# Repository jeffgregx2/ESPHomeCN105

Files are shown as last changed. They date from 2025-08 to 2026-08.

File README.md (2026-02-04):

# Mitsubishi CN105 ESPHome Hardware Microcontroller

This project is inspired by the work done by [@echavet](https://github.com/echavet/MitsubishiCN105ESPHome) and [@GeoffDavis](https://github.com/geoffdavis/esphome-mitsubishiheatpump) (and others) reverse engineering the CN105 serial protocol for the Mitsubishi Split-Mini heat pumps.  Their work allows for complete control of those units via ESPHome instead of the Kumo Cloud offering from Mitsubishi.  One can argue that the ESPHome offering is superior including the ability to have complete control over important logic such as room temperature settings, etc.

## Quick Links

 - Setting up ESPHome/Home Assistant - [Configuration](/home_assistant/)
 - Pre-made Hardware - [ETSY]() (Coming Soon) 
 - Building the Hardware - DIY/PCBWay:  
    - [PAC-USWHS002-WF-1 Compatible module](https://www.pcbway.com/project/shareproject/Mitsubishi_ESPHome_CN105_Microcontroller_kicad_pcb_b5b72995.html)
    - [PAC-USWHS002-WF-2 Compatible module](https://www.pcbway.com/project/shareproject/Mitsubishi_ESPHome_CN105_Microcontroller_PAC_USWHS002_WF_2_plug_compatible_8670e686.html)

## Hardware
In order to use the ESPHome approach, appropriate hardware needs to be assembled and installed in (or next to) each split-mini to be controlled.  Most take DevKits and breadboards or otherwise construct controllers to be installed.  However I wanted something more production ready that was plug compatible with the Mitsubishi PAC-USWHS002-WF-1 and PAC-USWHS002-WF-2 wifi modules and had the exact same footprint allowing easy swapping between modules.

To this end I have designed a PCB board using an ESP32-C6 devkit and associated 3D printed case that is the same size of the module it is replacing as well as plug compatible.  If you already have the PAC-USWHS002-WF-1 or WF-2 module installed, you can simply unplug that module and plug this new module into its place.  In addition, this new module exposes an i2c port via a [STEMMA](https://learn.adafruit.com/introducing-adafruit-stemma-qt/what-is-stemma) compatible connector.   For more information on the PCB design, 3D case, etc. and how to create your own copy of the board please see [PCB_assembly](/pcb_assembly/).

## Software

In addition, I have included ESPHome include files that allow assembling thermostat devices for this device in Home Assistant far easier and repeatable - very helpful if you have multiple devices.  The result allows for YAML files that only contain substitutions and secret references.  The files and additional documentation is available [HERE](/home_assistant/).

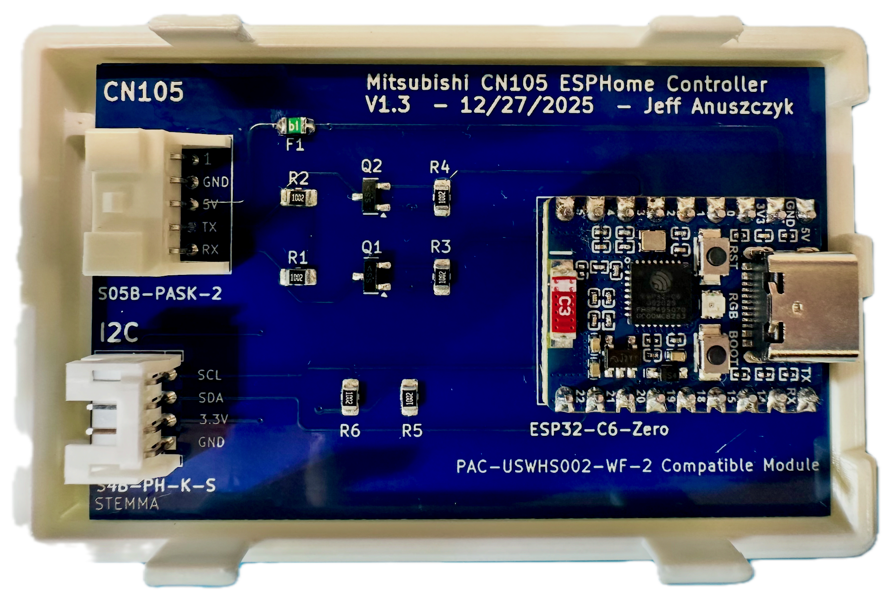
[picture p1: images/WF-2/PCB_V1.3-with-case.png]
PCB Board described above


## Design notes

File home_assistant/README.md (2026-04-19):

# ESPHome - Home Assistant Support
Once you have the appropriate hardware to support the ESPHomeCN105 firmware, you need to setup the appropriate YAML files in ESPHome.  In my case this is attached to [Home Assistant](https://www.home-assistant.io) making it effortless to both interact as well as make other devices available such as temperature sensors.  While you may only have one (1) split-mini wall unit, once you have two (2) or more units setting up the configurations can result in lots of duplication, etc. between the various YAML files.  To help minimize this I have created a set of include files that hopefully make reuse across multiple device simple and straightforward.  

All of the configuration needed to use these include files is done via the substition command within ESPHome YAML files. This allows for high reusability of code within the devices being created which will hopefully reduce bugs and enable the devices to behave similarly.

Please note that these files are aligned to the hardware described in [PCB_assembly](/pcb_assembly/) and specifically the use of the ESP32-C6 dev kit.  If you are using different hardware slight tweaks will be required.

##  Overview
The functionality provided by the defined YAML files includes:
* Climate device for Mitsubishi CN105 split-mini
* LED status indicator: Red = not connected to CN105, Green = Connected : blinks every 1.5 seconds
* Home Assistant API integration
* Remote Temperature sensor definition and logic to update CN105 periodically to ensure split-mini internal sensor is not used if a valid remote sensor value is available.
* i2c bus initialization to allow i2c sensors to be installed and used
* Various diagnostic information reported to Home Assistant

There are multiple include files that break up the functionality allowing you to load those portions that you need.  These files are as follows:
* **mitsubishi_cn105_device_base.yaml** - Required - this is the core include file that you must always load containing all of the climate device definitions. 
* **mitsubishi_cn105_config.yaml** - Required - this contains the hardware module definitions, logging, web server definitions as well as home assistant integration.  Note that this file is aligned to the ESP32-c6 dev kit and would need modification to work with other boards.
* **One of the following:**
	* **mitsubishi_cn105_remote_temp.yaml** -  this connects to a home assistant device that will provide temperature sensor information that will be used to set the remote temperature in the climate device. 
	* **mitsubishi_cn105_remote_temp_dual.yaml** - a more sophisticated version of mitsubishi_cn105_remote_temp.yaml that support two (2) remote sensor devices that can be setup as either a primary/backup configuration or an average of the two.  This is useful in situations in which one of the sensors is not entirely accurate but you would prefer an external temperature vs the internal sensor from the split mini (which tends to not be accurate).
	* **mitsubishi_cn105_remote_temp_none.yaml** - indicates that no remote temperature device will be used.
* **One of the following:**
   Since WiFi is required, either the static or dynamic configuration must be included (but only one of them!).
	* **mitsubishi_cn105_wifi_dynamic.yaml** - This include file sets up DHCP provisioning of the network address.  In many situations this is the best option.  If you have a "flat" network (i.e., home router/wifi that everything directly connects to) this will work well.
	* **mitsubishi_cn105_wifi_static.yaml** - This include file sets up the use of static IP address for the device - DHCP is disabled!  If you have separated your ESPHome/IoT devices into a different network (VLAN, etc.) assigning static IP addresses is by far the best approach to ensure reliable connection via the ESPHome Builder.  It will require you recording the IP addresses you have assigned to ensure that two devices don't get the same IP address (this will break things).

While this looks like a lot, take a look at the examples which will demonstrate usage that is hopefully very straightforward.

## Installation
There are two ways you can use the include files in your Home Assistant configuration:
1. **REMOTE** - Referenced directly from the files stored in GitHub, nothing is installed locally except for the device's YAML file.  The primary advantage is nothing to install locally, just create the normal device YAML file and reference the GitHub include files.  Unless you plan on making local changes this is likely the best approach.
2. **LOCAL** - Installed directly in Home Assistant and locally referenced within a device's YAML file.  The examples in this README are using local copies of the files.  The primary advantage to using local files is the ability to make local changes to core files.  However it requires substantially more work to deploy new updates from GitHub should they occur since you need to merge the changes together.

### Installing locally
In order to reference the include files in your device YAML file, you need to place all of the files located at [home_assistant/common](/home_assistant/common/) into an appropriate location in Home Assistant using either the terminal or a tool such as the [File Editor Add-On](https://github.com/home-assistant/addons?tab=readme-ov-file).

It is recommended that you copy the files to homeassistant/esphome/common (creating the 'common' directory first).  Once you have uploaded the files you should see them as follows (this examples uses File Editor):

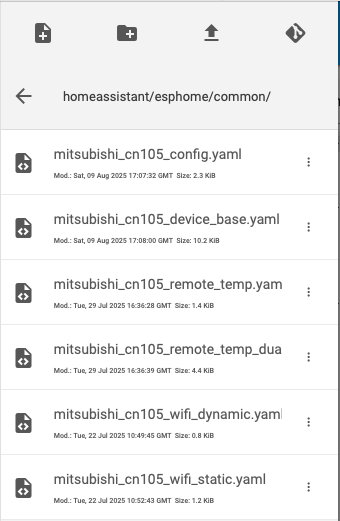
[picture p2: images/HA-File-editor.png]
File Editor example


## Simple Usage
In the simplest of cases, you can define a climate device with no remote sensors as follows:
### Remote include files
```
#
# Load the device configuration for Mitsubishi CN105 Controller.  This is a direct
# replacement for Mitsubishi Kumo Cloud Wifi Controller (Model PAC-USWHS002-WF-1/WF-2)
#
packages:
  - github://jeffgregx2/ESPHomeCN105/home_assistant/common/mitsubishi_cn105_config.yaml@v1.2
  - github://jeffgregx2/ESPHomeCN105/home_assistant/common/mitsubishi_cn105_wifi_dynamic.yaml@v1.2
  - github://jeffgregx2/ESPHomeCN105/home_assistant/common/mitsubishi_cn105_remote_temp_none.yaml@v1.2
  - github://jeffgregx2/ESPHomeCN105/home_assistant/common/mitsubishi_cn105_device_base.yaml@v1.2

# The packages have requirements regarding substitutions that need to be answered.
substitutions:
  name: midu-climate-guest-bedroom
  friendly_name: Mitsubishi Guest Bedroom
  
  # Wifi Setup - static configuration
  wifi_ssid: !secret wifi_iot_ssid
  wifi_password: !secret wifi_iot_password

  # Wifi Access Point Fallback
  wifi_ap_fallback_ssid: !secret fallback_ssid_midu_guest_bedroom
  wifi_ap_fallback_password: !secret fallback_password_midu_guest_bedroom

  # Various passwords
  api_key: !secret api_key_midu_guest_bedroom
  ota_key: !secret ota_key_midu_guest_bedroom

  # Setup web server authentication
  # To disable the web server add the following after the substitution section:
  #     web_server: !remove
  ws_username: !secret web_server_username
  ws_password: !secret web_server_password

 # Disable the web server component
web_server: !remove
```
Please note the '@v1.2' indicates that you only want version 1.2.  If you are not familiar with Git, this is a "tag" that was created to mark files at a specific point in time with a name (in this case "v1.2").  If you use "@main" then you would be using the latest version available in the repository.  By specifying a specific version you reduce the chances of breaking changes within the include files.  However you might miss an enhancement or a fix needed to maintain compatibility with the ESPHome and Home Assistant requiring manual intervention.

### Local include files
The only changes necessary to move to a local directory are in the packages definition:
```
packages:
  - !include common/mitsubishi_cn105_config.yaml
  - !include common/mitsubishi_cn105_wifi_dynamic.yaml
  - !include common/mitsubishi_cn105_remote_temp_none.yaml
  - !include common/mitsubishi_cn105_device_base.yaml
```
The directory specified must match the location you copied in the files in the [Installing Locally](#installing-locally) section.

## Detailed Examples
Click [HERE](/home_assistant/examples/) or more detailed examples

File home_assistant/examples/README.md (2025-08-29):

# Mitsubishi CN105 ESPHome - Examples
For simplicity, all examples use the Secret facility to store the differences between devices.  Mostly these are usernames and passwords - however they can include things like wifi SSID, etc.  Since these examples are public using Secrets allows for valid values while minimizing my ability to accidentally reveal information :-)

This directory provides the following examples:
* **midu-climate-simple.yaml** - essentially the minimal amount needed to setup a Mitsubishi Split Mini using the [ESPHomeCN105 firmware](https://github.com/echavet/MitsubishiCN105ESPHome).  This will require the include files to be [installed](/home_assistant/README.md#installing-locally) on your local Home Assistant server.  No temperature sensor is provided - only the internal sensor on the split mini will be available.
* **midu-climate-simple-git.yaml** - the same example as midu-climate-simple.yaml, except using GitHub to serve the include files instead of installing them locally.
* **midu-climate-simple_i2c.yaml** - the simple example now leveraging an i2c temperature sensor to set the local temperature instead of a Home Assistant sensor.
* **climate-simple-remote-temp.yaml** - the simple example with an added Home Assistant temperature sensor providing the temp to use in place of the split mini internal sensor.
* **midu-climate-dual-sensor.yaml** - a slightly more complex example in which two (2) Home Assistant temperature sensors are providing the temp to use in place of the split mini internal sensor.  The example averages the two temp together (if they are both available, if only one is available it alone is used).
* **midu-climate-complex-temp.yaml** - this demonstrates handling multiple temperature sensors within the device YAML exclusively adding more complex logic that decides what to do based upon the status of the split mini.
* **midu-climate-wifi-static.yaml** - all prior examples use dynamic WIFI (i.e., DHCP) to get an IP address on your network.  This example moves to static IP addresses which is highly useful when you have multiple subnets that are firewalled from each other.  This can cause mDNS (i.e., Bonjour) to not be available and thus the communications between HA/ESPHome to not be reliable (or work).  If you are using static IP addresses it is strongly advised that you also define a domain name via the wifi_domain variable.  The default is '.local' which is aligned with mDNS and may cause discovery to still not work.

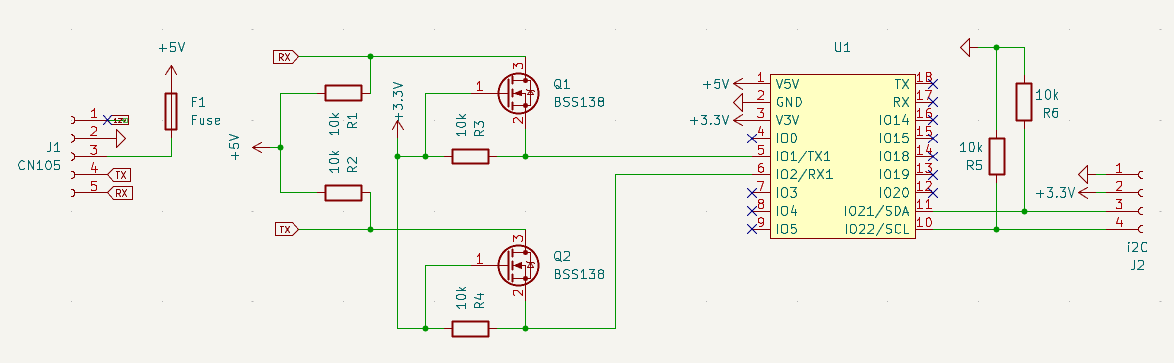
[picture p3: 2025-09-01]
images/WF-1/PCB-schematic.png

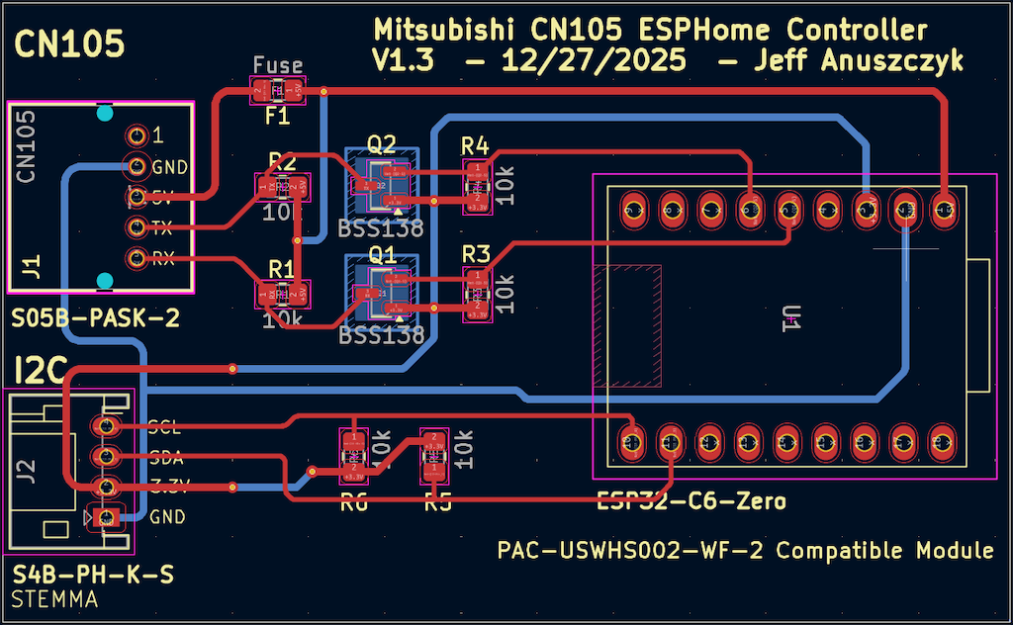
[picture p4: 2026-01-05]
images/WF-2/PCB-V1.3-layout.png

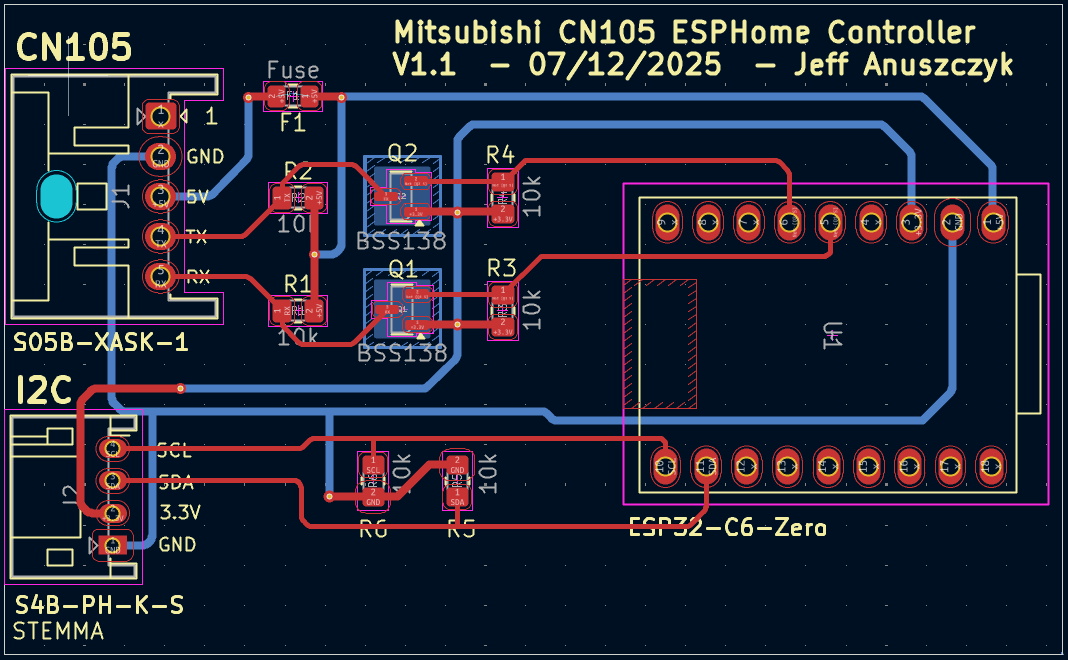
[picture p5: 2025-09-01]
images/WF-1/PCB-layout.png

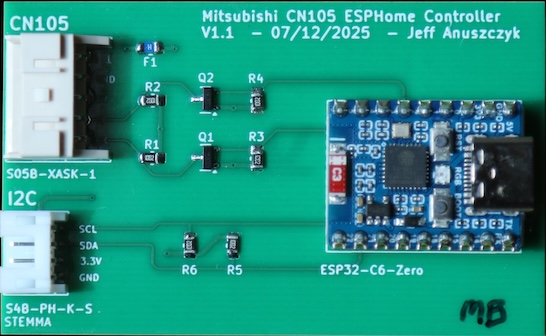
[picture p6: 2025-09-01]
images/WF-1/PCB-photo-S.jpg

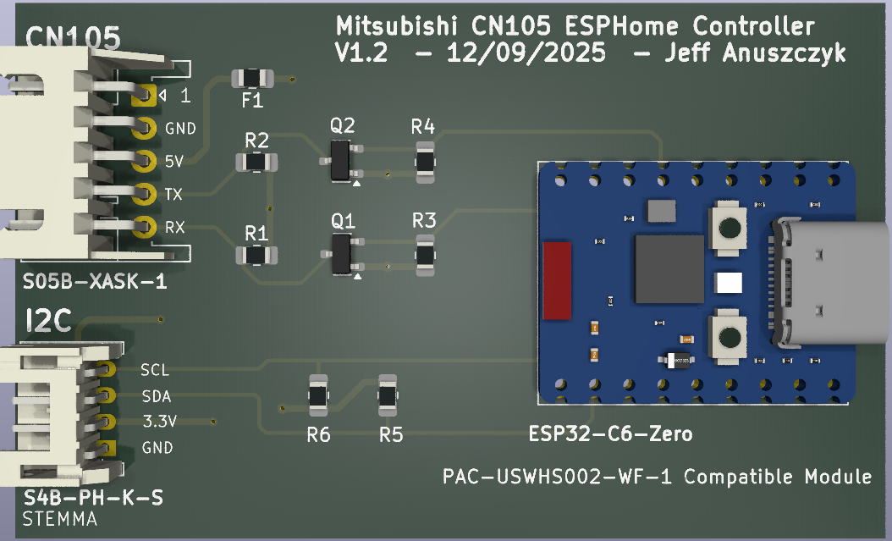
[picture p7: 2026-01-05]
images/WF-1/WF-1-PCB-V1.2.png

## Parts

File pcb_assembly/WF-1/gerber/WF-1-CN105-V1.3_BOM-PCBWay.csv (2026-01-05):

Designator | Quantity | Value | Footprint | Package | MPN | DNP | Mount_Type | Description | Manufacturer | Model | PCBWay_Part_Num
F1 | 1 | Fuse | Fuse_0805_2012Metric_Pad1.15x1.40mm_HandSolder |  |  |  | smt | Fuse | Vishay | MFU0805FF01000P500 | MFU0805FF01000P500
J1 | 1 | CN105 | JST_XA_S05B-XASK-1_1x05_P2.50mm_Horizontal |  |  |  | tht | Generic connector, single row, 01x05, script generated | JST | S05B-XASK-1 | S05B-XASK-1(LF)(SN)
J2 | 1 | i2C | JST_PH_S4B-PH-K_1x04_P2.00mm_Horizontal |  |  |  | tht | JST PH 4-pin edge connector | JST | S4B-PH-K-S | S4B-PH-K-S(LF)(SN)
Q1, Q2 | 2 | BSS138 | SOT-23 |  |  |  | smt | 50V Vds, 0.22A Id, N-Channel MOSFET, SOT-23 | Onsemi | BSS138 | BSS138CT-ND
R1, R2, R3, R4, R5, R6 | 6 | 10k | R_0805_2012Metric_Pad1.20x1.40mm_HandSolder |  |  |  | smt | Resistor | TE Connectivity | CRGCQ0805F10K | A129761CT-ND
U1 | 1 | ESP32-C6-Zero | Waveshare-ESP32-C6-Zero |  |  |  | tht |  | Waveshare | ESP32-C6-Zero | ESP32-C6-Zero-M

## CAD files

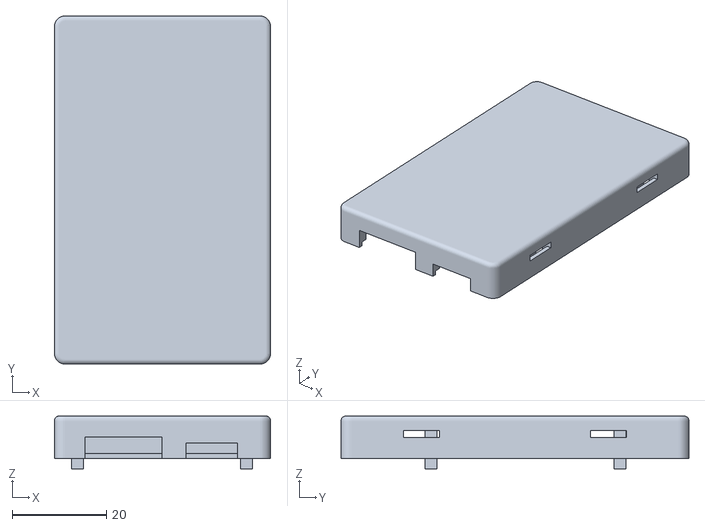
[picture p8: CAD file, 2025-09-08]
pcb_assembly/WF-1/3d_case/WF-1-CN105-v1.1-case_top.stl
46.0 x 74.0 x 11.2

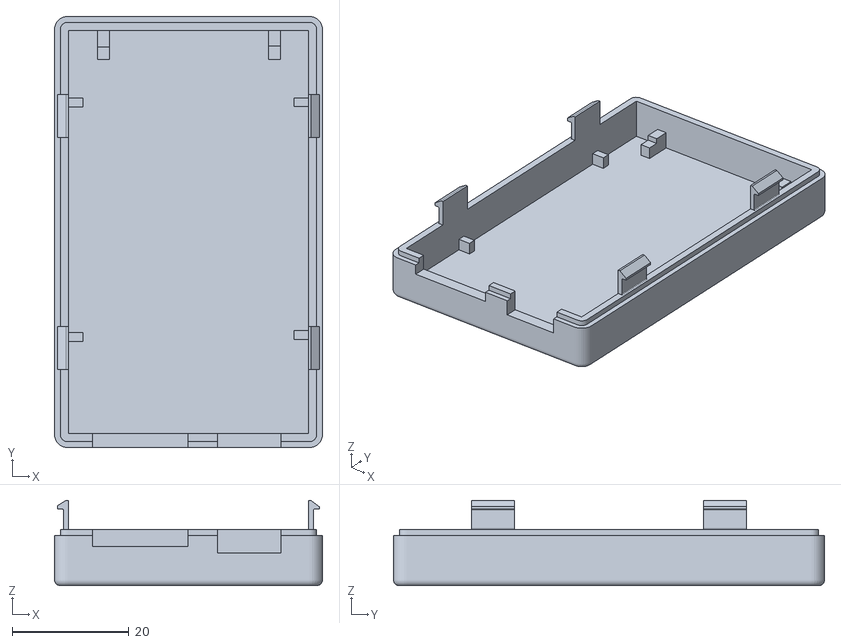
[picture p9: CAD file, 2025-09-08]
pcb_assembly/WF-1/3d_case/WF-1-CN105-v1.1-case_bottom.stl
46.0 x 74.0 x 14.7

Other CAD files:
pcb_assembly/WF-2/3d_case/WF-2-CN105-v1.3-case_top.stl
pcb_assembly/WF-2/3d_case/WF-2-CN105-v1.3-case_bottom.stl

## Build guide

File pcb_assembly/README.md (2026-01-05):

# Mitsubishi CN105 ESPHome Hardware - PCB

The purpose of this project was to provide a production level microcontroller capable of running the ESPHome firmware controlling the Mitsubishi spit-mini heat pumps.  It was important that the hardware be robust and is expected to run for the life of the split-mini system.  A breadboard or other approach didn't work for me.

The other reason I created this project is I had never built any type of PCB-level hardware before.  Thus it was an opportunity to learn new skills (circuit design, KiCad, etc).  For those of you more skilled than I, all of the mistakes and design failures due to lack of knowledge that you find I would love to hear about - just be aware that I started totally clueless (and generally I still am).  

## Features
During the design of my module I wanted the following features:

 - Plug compatible with the cable provided by Mitsubishi when using the PAC-USWHS002-WF-1 & WF-2 wifi modules.  It must be possible to simply unplug the PAC module and plug in this replacement module with no other changes.
 - Low heat generation - thus selection of 5v instead of 12v to avoid the added heat generation converting from 12v to 5v/3.3v.
 - Low power usage - since we don't know the actual power available on the 12v/5v power pins on the CN105 connector the goal is to keep the average/max power level as low as possible.
 - Modern hardware - leverage the most modern CPU hardware with low power usage.
 - Provide expansion capability via an exposed i2c port.
 - Ensure selected connectors are robust and lock in - avoid heat expansion/contraction disconnects.
 - Creation of a case that matches the case housing the PAC module.
 - Ensure that the entire project can be hand soldered.

It is definitely possible to create a smaller footprint project (likely 40% smaller), however it wasn't clear to me that it would gain anything especially since I wanted the module to be accessible after installation and thus within the access panel (of the units I own).  Since the PAC modules fit keeping that form factor would also fit.  Plus it would make soldering easier (not to be underestimated).

## Schematics
With this in mind I created the following schematic:

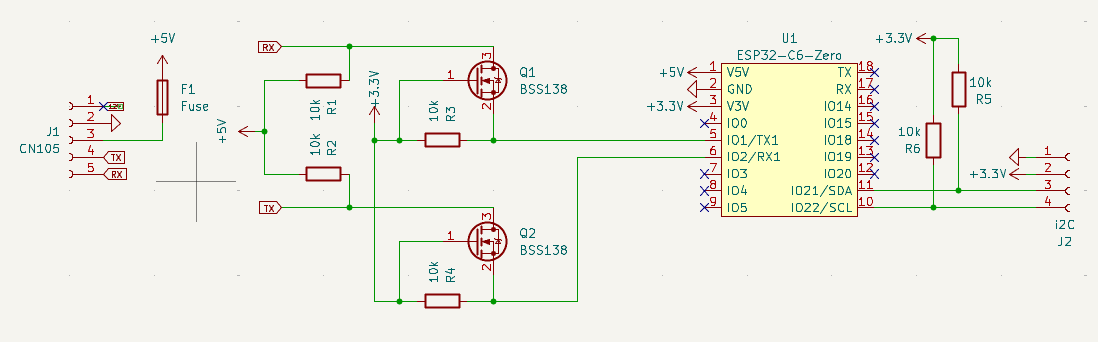
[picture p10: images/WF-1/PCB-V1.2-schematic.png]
PCB Schematic Diagram


Clearly this is a relatively simple design.  The most important elements are the inclusion of level shifters to convert from 5v <-> 3.3v ensuring that the CPU and CN105 voltages are appropriately accommodated.

## Layout

The next step is to design a 2-layer PCB that supports the above schematic.  Some care was taken to minimize the interference with the WiFi antenna.

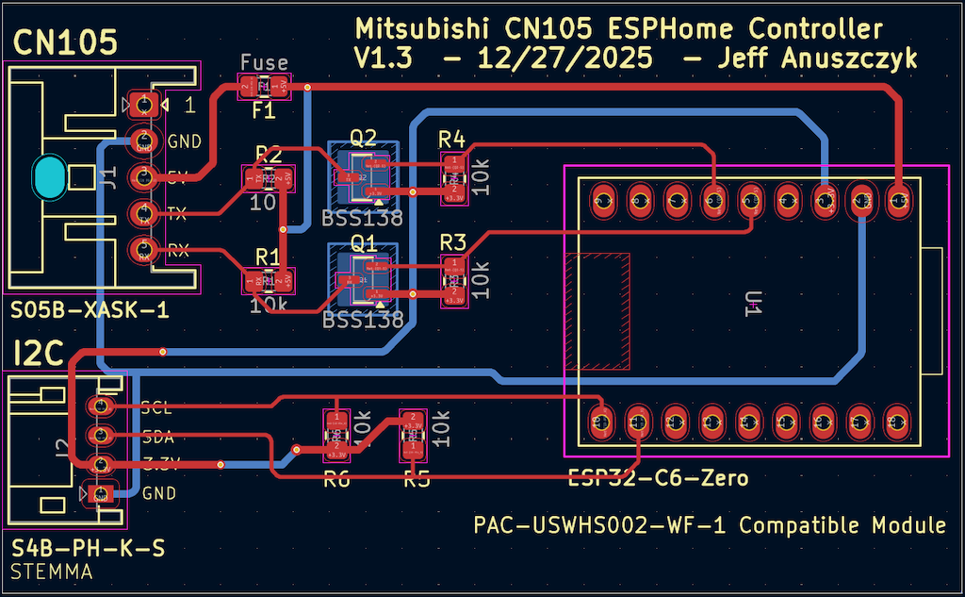
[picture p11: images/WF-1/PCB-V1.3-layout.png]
PCB Layout Diagram


## Model Differences

Mitsubishi has released multiple PAC modules over the past few years compatible with the Mitsubishi Kumo Cloud smart control system for their ductless mini-split HVAC systems.   The last two released versions are as follows:

<html><table>
<tr><td>
<b>PAC-USWHS002-WF-1</b><br>
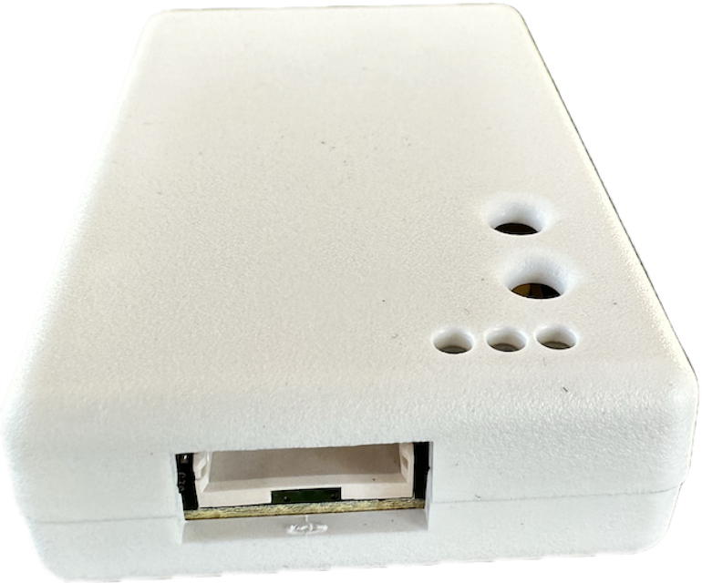
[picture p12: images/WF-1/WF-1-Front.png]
Single connector view
<br>
Note that the WF-1 has a single connector - JST XA 2.5mm pin spacing
</td>
<td>
<b>PAC-USWHS002-WF-2</b><br>
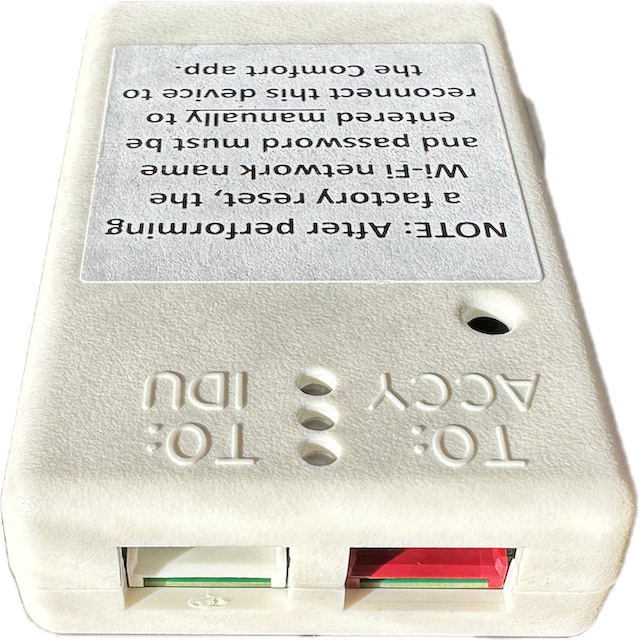
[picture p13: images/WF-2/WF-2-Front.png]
Dual connector view
<br>
The WF-2 has dual connectors - JST PA 2.0mm pin spacing
</td></tr>
</table>
</html>
It is important to note that the two modules do NOT use the same sized connector and thus the cables for them are not directly compatible (without an adapter).  If you wish to use this project confirm which version you need by looking at the module number on the PAC module and/or confirming with the connectors on the module.

## Moving Ahead
For instructions on how to build a version of this project compatible with your split-mini model click on the model number:
- [PAC-USWHS002-WF-1](/pcb_assembly/WF-1)
- [PAC-USWHS002-WF-2](/pcb_assembly/WF-2)

These instructions include links to PCBWay to simplify creating the PCB/obtaining fully assembled modules for a very modest price.  They also include all files necessary to use other fabricators.  For those of you comfortable with soldering size 805 SMT components this project is very approachable.  That said, you will likely need some level of magnification unless you have superior eyesight (I do not).

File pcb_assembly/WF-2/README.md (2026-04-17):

## Instructions for PAC-USWHS002-WF-2 compatible module

A reminder of the module:
<html><table><tr>
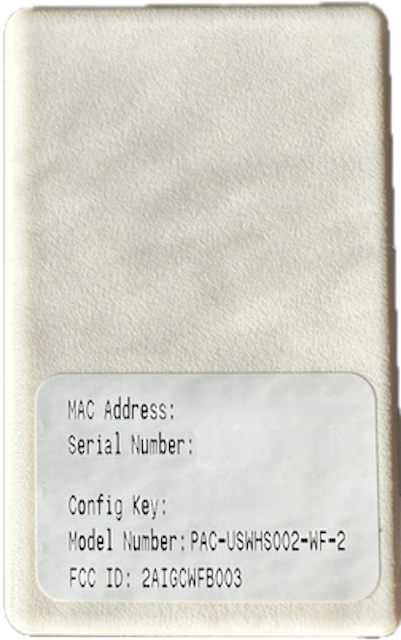
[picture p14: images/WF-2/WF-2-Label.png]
Label View
  <td></td>
  <td>Front View</td>
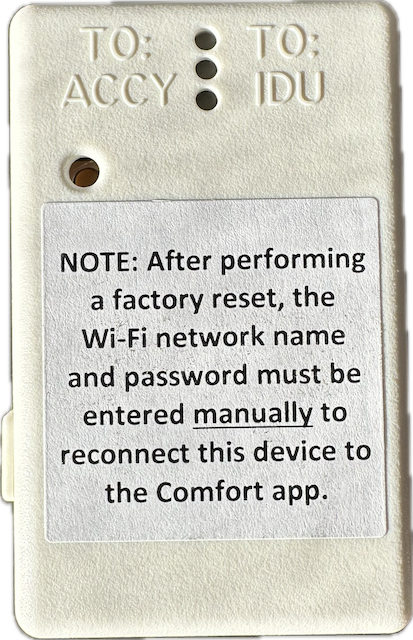
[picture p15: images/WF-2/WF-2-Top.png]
Top View
  <td></td>
</tr></table></html>  

Remember the CN105 wire harness provided with the WF-2 is not compatible with the connector on the WF-1 without an adapter cable.  Please ensure you select the correct version of this project to ensure connector compatibility.

## Fabrication

PCB Manufacturing can be accomplished using whichever fabricator you wish.  For convenience, a [PCBWay](https://www.pcbway.com/project/shareproject/Mitsubishi_ESPHome_CN105_Microcontroller_PAC_USWHS002_WF_2_plug_compatible_8670e686.html) 
project has been created that makes creating the PCB basically one click using PCBWay as the fabricator.   This option allows you to either create PCBs that you assemble using the parts below, or have the boards fully assembled so you just program and plugin.  You can also allow download of all gerber files, etc. in case you want to use a different vendor. 

A copy of all files also exists here: [Gerber files](/pcb_assembly/WF-2/gerber).  These should be identical to the ones at PCBWay - they are insurance in case
something happens to the PCBWay community site.  If you notice any discrepancy please let me know.

The supplied gerber files should be portable to any manufacturer not just PCBWay.

Version History
- V1.0 - 06/01/2025 - Initial Version
- V1.1 - 07/12/2025 - Fix issue in which i2c connector is reversed
- V1.2 - 12/09/2025 - Fix issue in which SDA/SDL need to be pulled high NOT low
- V1.3 - 12/27/2025 - Fork of WF-1 board to change connector to JST PA 2.0mm spacing

Please ensure you are using the latest version of the gerber files.

### Parts lists
|Qty|Part Desc.|Link|
|--|--|--|
| 1 | CN105 Connector | [S05B-PASK-2](https://www.digikey.com/en/products/detail/jst-sales-america-inc/S05B-PASK-2/926756) |
| 1 | I2C/Stemma | [S4B-PH-K-S](https://www.digikey.com/en/products/detail/jst-sales-america-inc/S4B-PH-K-S/926628) |
| 1 | Wavemaker ESP32-C6-Zero | [ESP32-C6-Zero-M](https://www.amazon.com/dp/B0D1K19W2Y?ref_=ppx_hzsearch_conn_dt_b_fed_asin_title_1) |
| 1 | 1A 32V Fuse | [MFU0805FF01000P500](https://www.digikey.com/en/products/detail/vishay-beyschlag-draloric-bc-components/MFU0805FF01000P500/1202619) |
| 6 | RES 10K OHM 1% 1/8W | [CRGCQ0805F10K](https://www.digikey.com/en/products/detail/te-connectivity-passive-product/CRGCQ0805F10K/8576363) |
| 2 | MOSFET N-CH 50V 220MA | [BSS138](https://www.digikey.com/en/products/detail/onsemi/BSS138/244210) |

The resulting assembled PCB should look like the following:

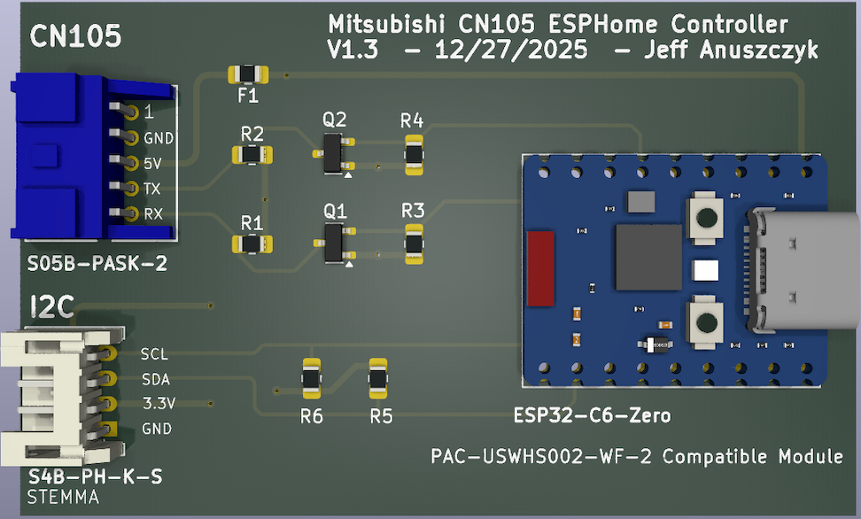
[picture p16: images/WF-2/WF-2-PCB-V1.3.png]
WF-2 Assembled


## Case
To complete the project I created a 3D printed case that is as close to the same dimensions as the original PAC wifi module.  It is a tooless design that simply snaps together (it does require a small screwdriver or really strong fingernails to disassemble).  

PCB in Case

The case was printed using white PLA using quality settings (0.2mm, 15% infill, no supports, etc.).  While there is a bit of play in the PCB restraint system, I did aim for precision to have the top/bottom snap to fit, etc.    You can find the STL files for the top & bottom of the case in the [3d_case](/pcb_assembly/WF-2/3d_case) directory.  If there is sufficient interest I can place them on printables.

## Final Notes

This project could be done with larger components, there is sufficient space.  However I wanted the opportunity to learn surface mount components and chose 805 size as a compromise.  It would also enable installation of some or all of the components at fabrication time if that was ever interesting to someone.

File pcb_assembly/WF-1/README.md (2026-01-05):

## Instructions for PAC-USWHS002-WF-1 compatible module

A reminder of the module:
<html><table><tr>
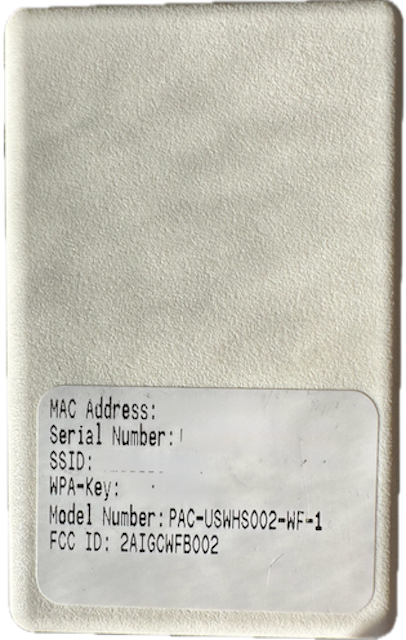
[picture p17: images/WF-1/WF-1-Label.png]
Label View
  <td></td>
  <td>Front View</td>
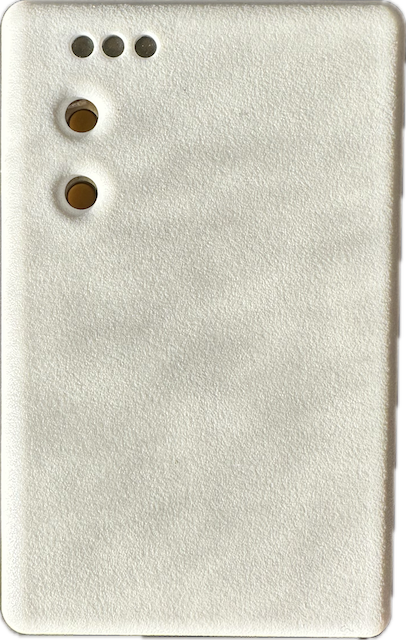
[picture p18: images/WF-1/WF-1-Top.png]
Top View
  <td></td>
</tr></table></html>  

Remember the CN105 wire harness provided with the WF-1 is not compatible with the connector on the WF-2 without an adapter cable.  Please ensure you select the correct version of this project to ensure connector compatibility.

## Fabrication
PCB Manufacturing can be accomplished using whichever fabricator you wish.  For convenience, a [PCBWay](https://www.pcbway.com/project/shareproject/Mitsubishi_ESPHome_CN105_Microcontroller_kicad_pcb_b5b72995.html) 
project has been created that makes creating the PCB basically one click using PCBWay as the fabricator.   This option allows you to either create PCBs that you assemble using the parts below, or have the boards fully assembled so you just program and plugin.  You can also allow download of all gerber files, etc. in case you want to use a different vendor. 

A copy of all files also exists here: [Gerber files](/pcb_assembly/WF-1/gerber).  These should be identical to the ones at PCBWay - they are insurance in case
something happens to the PCBWay community site.  If you notice any discrepancy please let me know.

The supplied gerber files should be portable to any manufacturer not just PCBWay.

Version History
- V1.0 - 06/01/2025 - Initial Version
- V1.1 - 07/12/2025 - Fix issue in which i2c connector is reversed
- V1.2 - 12/09/2025 - Fix issue in which SDA/SDL need to be pulled high NOT low 
- V1.3 - 12/27/2025 - Slight tweak to trace routing to stay in sync with WF-2, no real changes

Please ensure you are using the latest version of the gerber files.

### Parts lists
|Qty|Part Desc.|Link|
|--|--|--|
| 1 | CN105 Connector | [S05B-XASK-1](https://www.digikey.com/en/products/detail/jst-sales-america-inc/S05B-XASK-1/9951644) |
| 1 | I2C/Stemma | [S4B-PH-K-S](https://www.digikey.com/en/products/detail/jst-sales-america-inc/S4B-PH-K-S/926628) |
| 1 | Wavemaker ESP32-C6-Zero | [ESP32-C6-Zero-M](https://www.amazon.com/dp/B0D1K19W2Y?ref_=ppx_hzsearch_conn_dt_b_fed_asin_title_1) |
| 1 | 1A 32V Fuse | [MFU0805FF01000P500](https://www.digikey.com/en/products/detail/vishay-beyschlag-draloric-bc-components/MFU0805FF01000P500/1202619) |
| 6 | RES 10K OHM 1% 1/8W | [CRGCQ0805F10K](https://www.digikey.com/en/products/detail/te-connectivity-passive-product/CRGCQ0805F10K/8576363) |
| 2 | MOSFET N-CH 50V 220MA | [BSS138](https://www.digikey.com/en/products/detail/onsemi/BSS138/244210) |

The resulting assembled PCB should look like the following:

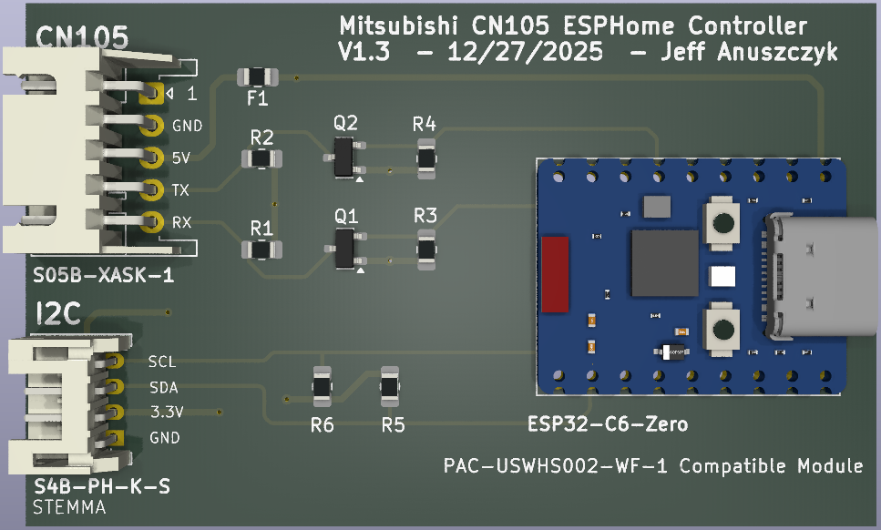
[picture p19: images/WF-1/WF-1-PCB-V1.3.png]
WF-1 Assembled


## Case
To complete the project I created a 3D printed case that is as close to the same dimensions as the original PAC wifi module.  It is a tooless design that simply snaps together (it does require a small screwdriver or really strong fingernails to disassemble).  

PCB in Case

The case was printed using white PLA using quality settings (0.2mm, 15% infill, no supports, etc.).  While there is a bit of play in the PCB restraint system, I did aim for precision to have the top/bottom snap to fit, etc.    You can find the STL files for the top & bottom of the case in the [3d_case](/pcb_assembly/WF-1/3d_case) directory.  If there is sufficient interest I can place them on printables.

## Final Notes

This project could be done with larger components, there is sufficient space.  However I wanted the opportunity to learn surface mount components and chose 805 size as a compromise.  It would also enable installation of some or all of the components at fabrication time if that was ever interesting to someone.

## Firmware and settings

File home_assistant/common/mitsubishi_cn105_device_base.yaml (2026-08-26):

#
# This package contains the actual definition and logic for the Mitsubishi CN105
# Device Controller.  Currently the expectation is we are going to be connected to
# Home Assistant and thus devices, etc. will be enabled including a remote temperature
# device.
#
# This package requires the following substitutions to be defined:
#
#  - Identification
#        name                     -> ESPHome name 
#        hp_name                  -> Climate name to use
#        hp_id                    -> Climate device ID - default hp_id
#        hp_F_compatibility       -> Use internal table for better temp compatibility - default standard
#        hp_update_interval       -> Interval between updates - split mini dependent - default 1.5s
#
#  - Device Setup
#        cn105_tx_pin             -> TX pin number for CN105 UART - default GPIO1
#        cn105_rx_pin             -> RX pin number for CN105 UART - default GPIO2
#        i2c_scl_pin              -> SCL pin number for i2c bus   - default GPIO22
#        i2c_sda_pin              -> SDA pin number for i2c bus   - default GPIO21
#        i2c_scan_bus             -> boolean to scan bus or not.  - default false
#        status_light_ctrl_pin    -> Pin number for RMT LED Strip - default GPIO8
#        status_light_brightness  -> Whole number percentage (0-100) for led brightness - default 25
#
#  - Controlling constants
#        rts_refresh_timeout      -> number of seconds with no update to trigger rta refresh
#  - Scripts
#        reevaluate_remote_temp   -> Script to recalculate remote temperature.  Needed on MODE change.

substitutions:
  # Climate Device ID & control settings
  hp_id: hp_id
  hp_name: None
  hp_F_compatibility: standard
  hp_update_interval: 1.5s
  
  # HP Uart GPIO pin selection
  cn105_tx_pin: GPIO1
  cn105_rx_pin: GPIO2
  i2c_scl_pin:  GPIO22
  i2c_sda_pin:  GPIO21
  i2c_scan_bus: false
  
  # Light ping & brightness level
  status_light_ctrl_pin: GPIO8
  status_light_brightness: 25
  
  # rts refresh timeout
  rts_refresh_timeout: 300
  
# Retrieve mitsubishi components
external_components:
  - source: github://echavet/MitsubishiCN105ESPHome
  #- source: github://GioMez/MitsubishiCN105ESPHome

# Setup boot initialization
esphome:
  on_boot: 
    priority: 100
    then:
      # Initialize the status light - red means not initialized
      - light.turn_on:
          id: status_led
          brightness: ${status_light_brightness}%
          red: 100%
          green: 0%
          blue: 1%
          effect: "Heartbeat"

# Define UART for CN105 interface
uart:
  id: HP_UART
  baud_rate: 2400
  tx_pin: ${cn105_tx_pin}
  rx_pin: ${cn105_rx_pin}

globals:
  # True if HA RTS value is available, false if HA announces the value is not "unavailable"
  - id: rts_temp_valid
    type: bool
    initial_value: "false"
  - id: rts_last_change_time
    type: long
    initial_value: "0"
  - id: hp_current_mode
    type: esphome::climate::ClimateMode

# Add support for i2c devices
i2c:
   - id: bus_a
     sda: ${i2c_sda_pin}
     scl: ${i2c_scl_pin}
     scan: ${i2c_scan_bus}
     frequency: 200kHz   # 50kHz, 100Hkz, 200kHz, 400Khz

light:
  - platform: esp32_rmt_led_strip
    id: status_led
    name: "Status Led"
    internal: true
    pin:
      number: ${status_light_ctrl_pin}
      ignore_strapping_warning: true
    num_leds: 1
    channel_colors: RGB
    chipset: WS2812
    default_transition_length: 0ms
    effects:
      - lambda:
          name: "Heartbeat"
          update_interval: 500ms
          lambda: |-
            static bool state = false;
            static unsigned long last_toggle = 0;
            static unsigned long on_time = 2000;
            static unsigned long off_time = 500;
            static unsigned long next_toggle = on_time;

            if (millis() - last_toggle >= next_toggle) {
              state = !state;
              last_toggle = millis();
              next_toggle = state ? on_time : off_time;
            }
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

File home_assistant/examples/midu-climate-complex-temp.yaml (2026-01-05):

#
# Load the device configuration for Mitsubishi CN105 Controller.  This is a direct
# replacement for Mitsubishi Kumo Cloud Wifi Controller.
#
# This configuration demonstrates how to explicitly define temperature sensors in this
# configuration file instead of via the include files.  This allows you to take complete
# control over the logic and do things like selecting data based upon split mini status.
# For example, in this case the remote_temp_sensor is a Z-wave line voltage thermostat
# that is unfortuntely directly opposite the split-mini wall unit.  This causes air travel
# over the temperature sensor that, when the fan is on higher settings, can misread the 
# actual room temperature.  The other sensor is battery powered and, while accurate, is
# not guaranteed to be present.  As such we want logic to ensure we select the "best"
# temperature from those that are available and influenced by the current split-mini
# status.
#
# It's important to note that the temperature you calculate should be communicated to the 
# underlying system by setting the internal template sensor "rts_effective_temp" to the
# calculated value as follows:
#
#    id(rts_effective_temp).publish_state(<calculated_value>);
#
# This sensor is what actually drives the underlying logic that causes the CN105 communications 
# to set the remote temp in the split mini.  If your device becomes unavailable you should 
# publishing NAN to indicate that you no longer have a valid value.  This will will ultimately 
# cause the split mini revert back to internal sensors.  There is already logic to handle the 
# case in which the temp is not changing but is valid (i.e., you have a valid temp it's just not changing).

#
packages:
  - !include common/mitsubishi_cn105_config.yaml
  - !include common/mitsubishi_cn105_wifi_dynamic.yaml
  - !include common/mitsubishi_cn105_device_base.yaml

  # Please note that no remote_temp.yaml file was loaded.  Instead we are explicitly defining
  # the functionality below (specifically the climate_mode_changed script).  Failure to do so 
  # would result in compilation errors.
 
# The packages have requirements regarding substitutions that need to be answered.
substitutions:
  name: midu-climate-living-room
  friendly_name: Mitsubishi Living Room
  remote_temp_sensor: sensor.living_room_thermostat_electric_air_temperature
  kitchen_temp_sensor: sensor.z2m_kitchen_temp_humidity_temperature

  # Wifi Setup - static configuration
  wifi_ssid: !secret wifi_iot_ssid
  wifi_password: !secret wifi_iot_password

  # Wifi Access Point Fallback
  wifi_ap_fallback_ssid: !secret fallback_ssid_midu_living_room
  wifi_ap_fallback_password: !secret fallback_password_midu_living_room

  # Various passwords
  api_key: !secret api_key_midu_living_room
  ota_key: !secret ota_key_midu_living_room

  # Setup web server authentication
  # To disable the web server add the following after the substitution section:
  #     web_server: !remove
  ws_username: !secret web_server_username
  ws_password: !secret web_server_password

# Disable the web server component
web_server: !remove

# Define the Home Assistant devices that we will be using to retrieve remote
# temperature readings.  Currently a remote temp sensor is required mostly due
# to the fact that the iSee sensor in the Mitsubishi unit is incredibly inaccurate.
# The original Kumo cloud implementation deployed with bluetooth temp/humidity
# sensors which dramatically improved things, this provides similiar functionality.
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

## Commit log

2025-08-29 Fix typos, change top level PCB image
2025-09-01 Add documentation for creating your own PCB
2025-09-02 Fix number of resistors
2025-09-08 Update PCB to include BOM, etc. Add 3D case stl files to allow case fabrication
    [CN105-v1.1-case_bottom.stl, CN105-v1.1-case_top.stl]
2025-12-09 Gerber files are the wrong version - syncing with PCBWay
2025-12-09 Fix minor extra wire in GND - cosmetic
2025-12-09 Update documentation to reflect new v1.2 schematic/nboard
2025-12-27 Inital creation of WF-2 compatible module
    [CN105-v1.1-case_bottom.stl, CN105-v1.1-case_top.stl]
2025-12-27 Changes to PCB silkscreen
2025-12-28 Add 3d rendering of PCB for better documentation
2025-12-28 Update PCB layouts to be consistent sizes, etc
2025-12-29 Update to latest gerber files
    [WF-1-CN105-V1.3_BOM-PCBWay.xls, WF-1-CN105-v1.1-case_bottom.stl, WF-1-CN105-v1.1-case_top.stl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]
2025-12-29 #6 - make Climate device name optional
    According to bug #6 and ESPHome documentation, you don't need to specify the Climate.name if ESPhome.name is set. This fix makes the default Climate.name unset giving users the option of setting the value if they so wish
    [mitsubishi_cn105_device_base.yaml]
2025-12-30 Lots of documentation tweaks, bug #6 fix
    [midu-climate-complex-temp.yaml]
2026-01-04 Final changes for boards sent to fabrication
    [WF-1-CN105-V1.3_BOM-PCBWay.csv, WF-2-CN105-V1.3_BOM-PCBWay.csv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]
2026-01-04 Fix PCB view - references were disabled
2026-01-25 Add test harness for board validation
2026-04-17 Suppress strapping warning
2026-04-17 Remove PCB Qualification statement - this completed on 01-31-2026
2026-05-17 Add missing WF-2 files
    [WF-2-CN105-v1.3-case_bottom.stl, WF-2-CN105-v1.3-case_top.stl]
2026-08-26 #17: Fix isUARTConnected_ rename issue; Fix deprecated rgb_order naming
    [mitsubishi_cn105_device_base.yaml]
